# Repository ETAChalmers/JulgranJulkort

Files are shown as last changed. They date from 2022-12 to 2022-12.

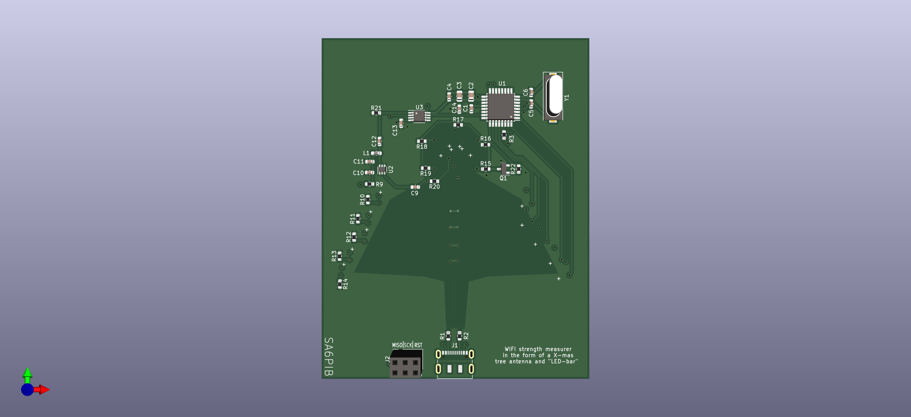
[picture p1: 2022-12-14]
ETA_JulkortB.png

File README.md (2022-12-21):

# X-mas tree card
# NOT TESTED (2022-12-21)
This PCB is a supposed to become a Christmas card from E-sectionens Teletekniska Avdelning (ETA). It is a 2,4 GHz antenna in the shape of a Christmas tree. According to the Wifi strength the card is exposed to, different LED's should light up, so it is basically a fancy bar graph.

ETA_JulkortF
ETA_JulkortB

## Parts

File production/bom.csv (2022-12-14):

Designator | Footprint | Quantity | Value | LCSC Part #
C1, C11, C4 | C_0603_1608Metric | 3 | 0,1 uF
C10 | C_0603_1608Metric | 1 | 100 pF
C12, C9 | C_0603_1608Metric | 2 | 1 nF
C13 | C_0603_1608Metric | 1 | C
C14 | C_0603_1608Metric | 1 | 0,01 uF
C2, C3 | C_0805_2012Metric | 2 | 4,7 uF
C5, C6 | C_0603_1608Metric | 2 | 22p
D1, D10, D11, D12, D13, D14, D15, D16, D2, D3, D4, D5, D6, D7, D8, D9 | LED_0805_2012Metric | 16 | LED
J1 | USB_C_Receptacle_JAE_DX07S016JA1R1500 | 1 | USB_C_Receptacle_USB2.0
J2 | PinSocket_2x03_P2.54mm_Vertical | 1 | Conn_02x03_Odd_Even
L1 | L_0603_1608Metric_Pad1.05x0.95mm_HandSolder | 1 | 28 nH
Q1 | SOT-23 | 1 | IRLML2803TR
R1, R2 | R_0603_1608Metric | 2 | 5,1k
R10, R11, R12, R13, R14, R15, R16, R17, R18, R19, R20 | R_0603_1608Metric | 11 | 500
R21, R22 | R_0603_1608Metric | 2 | 50
R3 | R_0603_1608Metric | 1 | 10k
R9 | R_0603_1608Metric | 1 | 30
U1 | TQFP-32_7x7mm_P0.8mm | 1 | ATmega88
U2 | SOT-363_SC-70-6 | 1 | AVT-51663_PIB
U3 | MSOP-8_3x3mm_P0.65mm | 1 | MAX4003
Y1 | Crystal_SMD_HC49-SD | 1 | 16MHz

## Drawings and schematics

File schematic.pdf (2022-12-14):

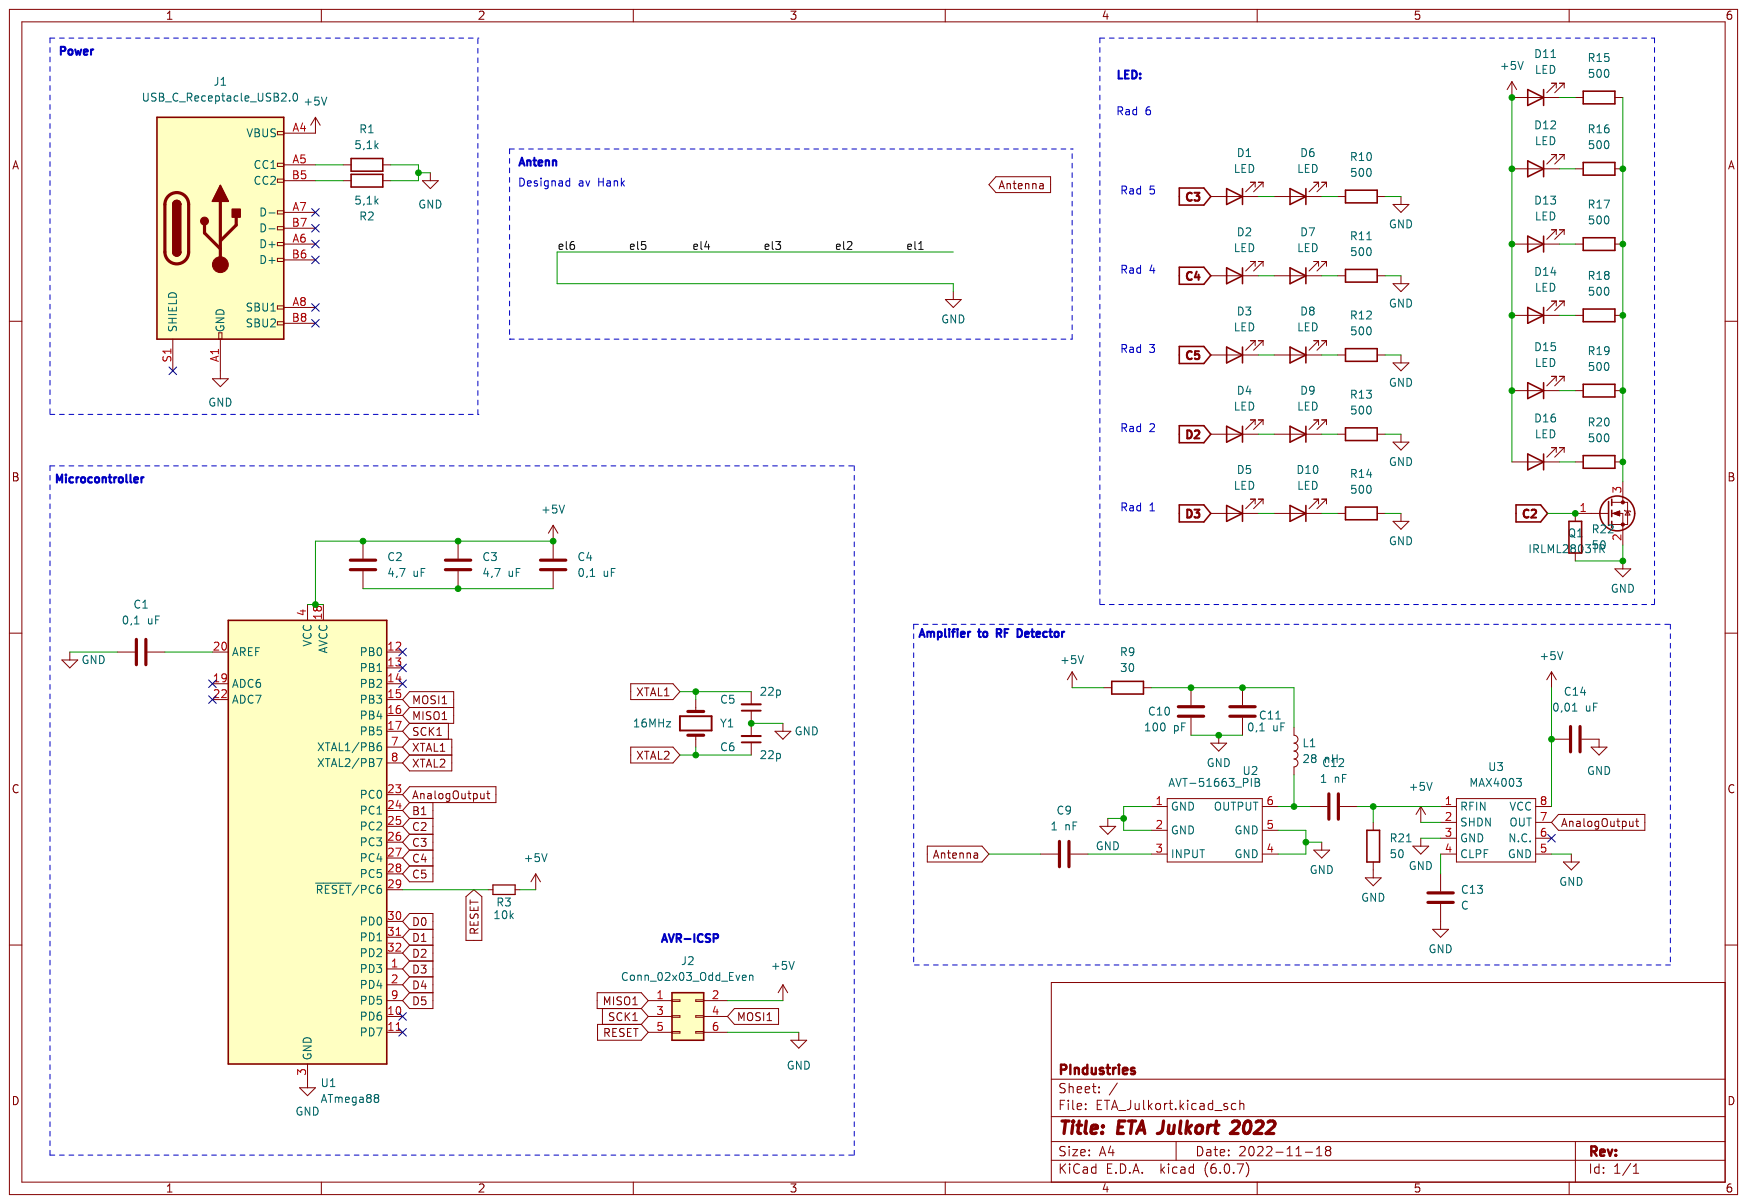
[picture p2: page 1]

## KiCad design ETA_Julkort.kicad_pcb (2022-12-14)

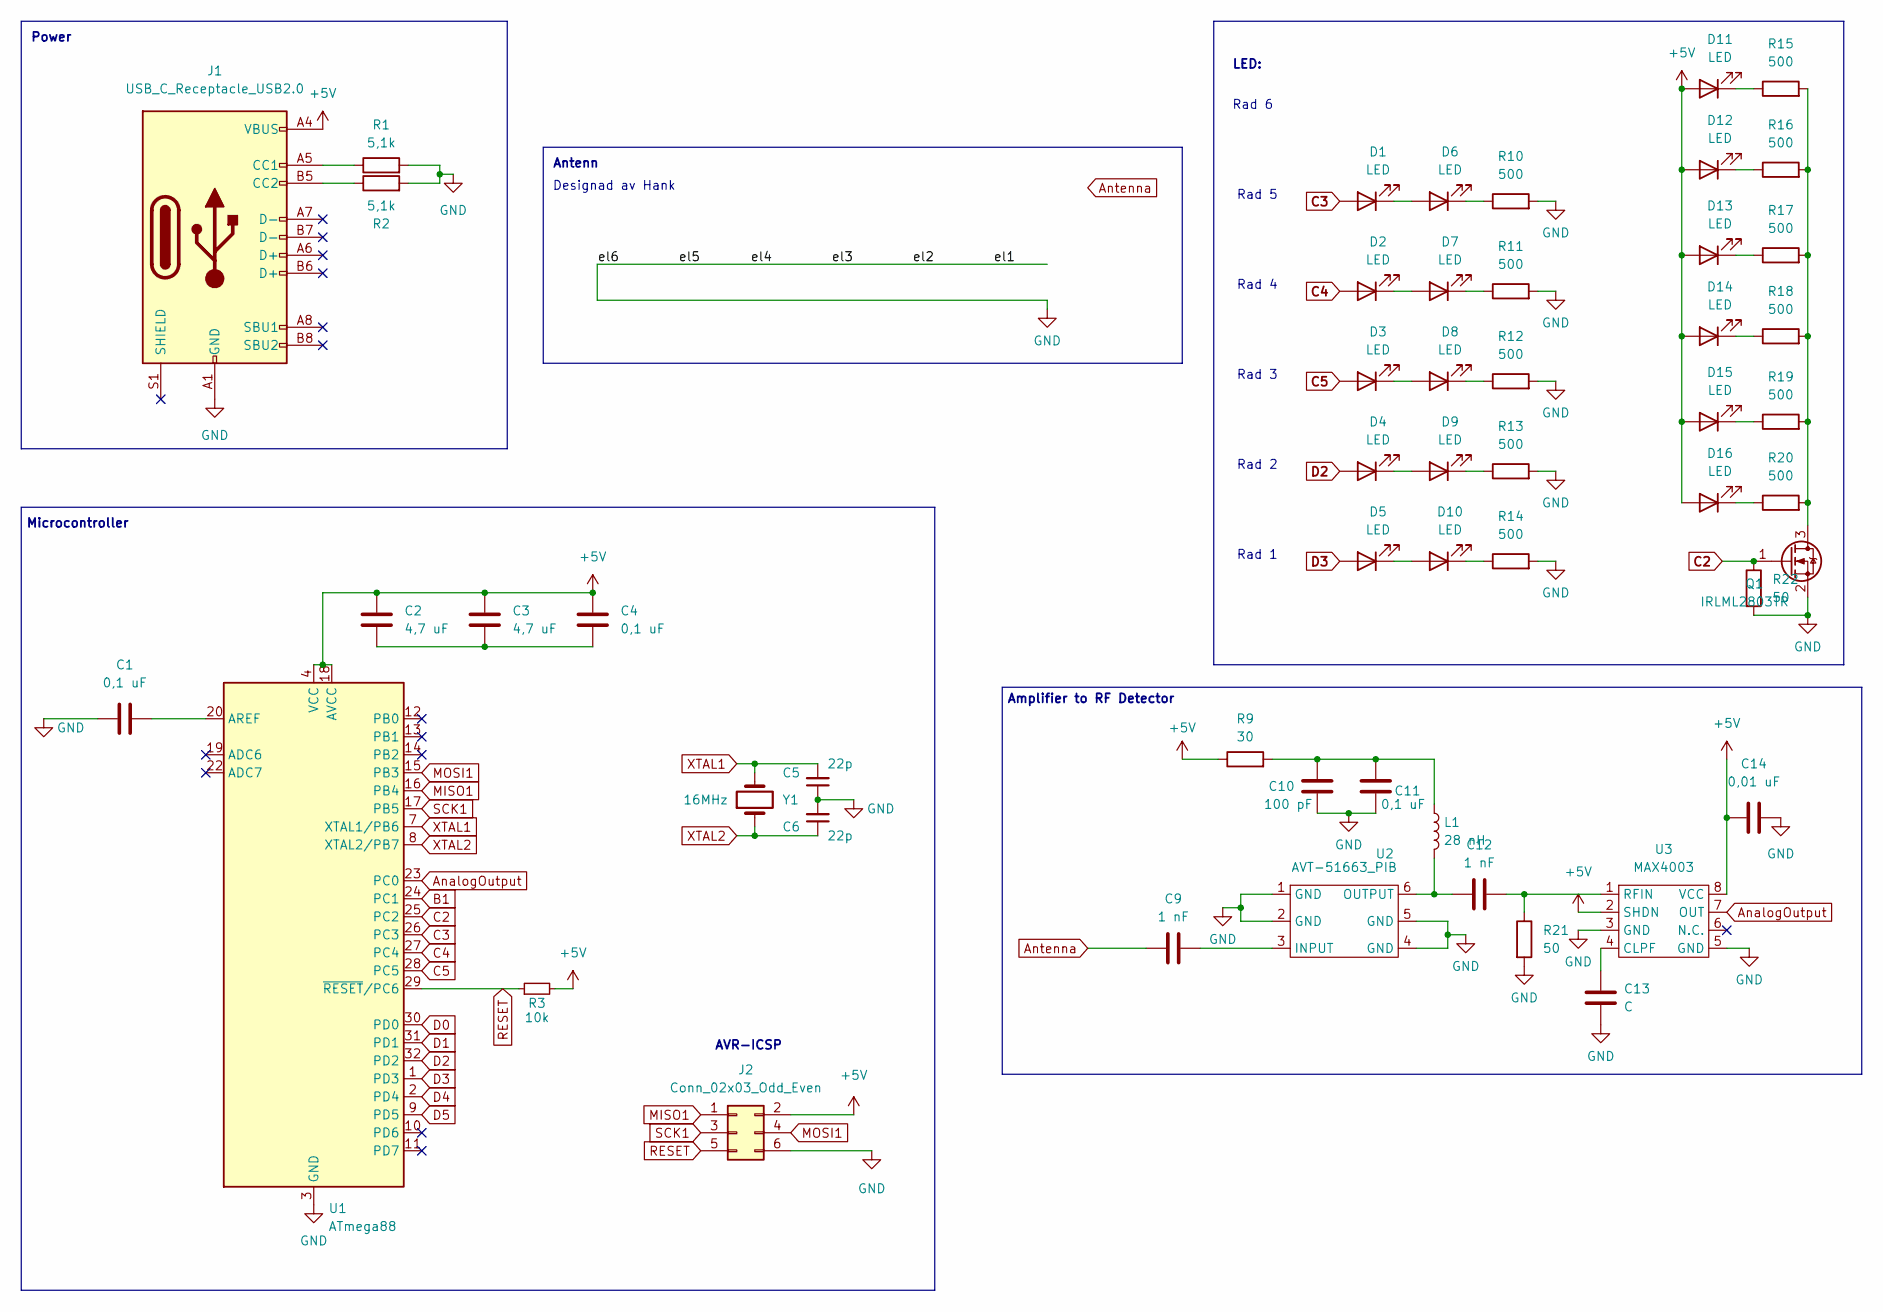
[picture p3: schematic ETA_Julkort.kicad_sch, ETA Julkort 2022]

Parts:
C1, C4, C11: 0,1 uF; C_0603_1608Metric
C2, C3: 4,7 uF; C_0805_2012Metric
C5, C6: 22p; C_0603_1608Metric
C9, C12: 1 nF; C_0603_1608Metric
C10: 100 pF; C_0603_1608Metric
C13: C; C_0603_1608Metric
C14: 0,01 uF; C_0603_1608Metric
D1, D2, D3, D4, D5, D6, D7, D8, D9, D10, D11, D12, D13, D14, D15, D16: LED; LED_0805_2012Metric
J1: USB_C_Receptacle_USB2.0; USB_C_Receptacle_JAE_DX07S016JA1R1500
J2: Conn_02x03_Odd_Even; PinSocket_2x03_P2.54mm_Vertical
L1: 28 nH; L_0603_1608Metric_Pad1.05x0.95mm_HandSolder
Q1: IRLML2803TR; SOT-23
R1, R2: 5,1k; R_0603_1608Metric
R3: 10k; R_0603_1608Metric
R9: 30; R_0603_1608Metric
R10, R11, R12, R13, R14, R15, R16, R17, R18, R19, R20: 500; R_0603_1608Metric
R21, R22: 50; R_0603_1608Metric
U1: ATmega88; TQFP-32_7x7mm_P0.8mm
U2: AVT-51663_PIB; SOT-363_SC-70-6
U3: MAX4003; MSOP-8_3x3mm_P0.65mm
Y1: 16MHz; Crystal_SMD_HC49-SD

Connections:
+5V: C2.1, C3.1, C4.1, C14.1, D11.2 (A), D12.2 (A), D13.2 (A), D14.2 (A), D15.2 (A), D16.2 (A), J1.A4 (VBUS), J1.A9 (VBUS), J1.B4 (VBUS), J1.B9 (VBUS), J2.2, R3.2, R9.1, U1.4 (VCC), U1.6 (VCC), U1.18 (AVCC), U3.2 (SHDN), U3.8 (VCC)
AnalogOutput: U1.23 (PC0), U3.7 (OUT)
B1: U1.24 (PC1)
C2: Q1.1 (G), R22.1, U1.25 (PC2)
C3: D1.2 (A), U1.26 (PC3)
C4: D2.2 (A), U1.27 (PC4)
C5: D3.2 (A), U1.28 (PC5)
D0: U1.30 (PD0)
D1: U1.31 (PD1)
D2: D4.2 (A), U1.32 (PD2)
D3: D5.2 (A), U1.1 (PD3)
D4: U1.2 (PD4)
D5: U1.9 (PD5)
MISO1: J2.1, U1.16 (PB4)
MOSI1: J2.4, U1.15 (PB3)
unnamed: C1.2, U1.20 (AREF)
unnamed: C2.2, C3.2, C4.2
unnamed: C9.2, U2.3 (INPUT)
unnamed: C10.1, C11.1, L1.1, R9.2
unnamed: C12.1, L1.2, U2.6 (OUTPUT)
unnamed: C12.2, R21.1, U3.1 (RFIN)
unnamed: C13.1, U3.4 (CLPF)
unnamed: D1.1 (K), D6.2 (A)
unnamed: D2.1 (K), D7.2 (A)
unnamed: D3.1 (K), D8.2 (A)
unnamed: D4.1 (K), D9.2 (A)
unnamed: D6.1 (K), R10.1
unnamed: D7.1 (K), R11.1
unnamed: D8.1 (K), R12.1
unnamed: D9.1 (K), R13.1
unnamed: D10.1 (K), R14.1
unnamed: D5.1 (K), D10.2 (A)
unnamed: D11.1 (K), R15.1
unnamed: D12.1 (K), R16.1
unnamed: D13.1 (K), R17.1
unnamed: D14.1 (K), R18.1
unnamed: D15.1 (K), R19.1
unnamed: D16.1 (K), R20.1
unnamed: J1.A5 (CC1), R1.1
unnamed: J1.B5 (CC2), R2.1
unnamed: Q1.3 (D), R15.2, R16.2, R17.2, R18.2, R19.2, R20.2
RESET: J2.5, R3.1, U1.29 (~RESET/PC6)
SCK1: J2.3, U1.17 (PB5)
XTAL1: C5.2, U1.7 (XTAL1/PB6), Y1.2
XTAL2: C6.1, U1.8 (XTAL2/PB7), Y1.1

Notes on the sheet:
Microcontroller
Rad 5
Rad 6
Designad av Hank
Amplifier to RF Detector
LED:
Rad 2
Antenn
Rad 4
Rad 1
Rad 3
AVR-ICSP
Power

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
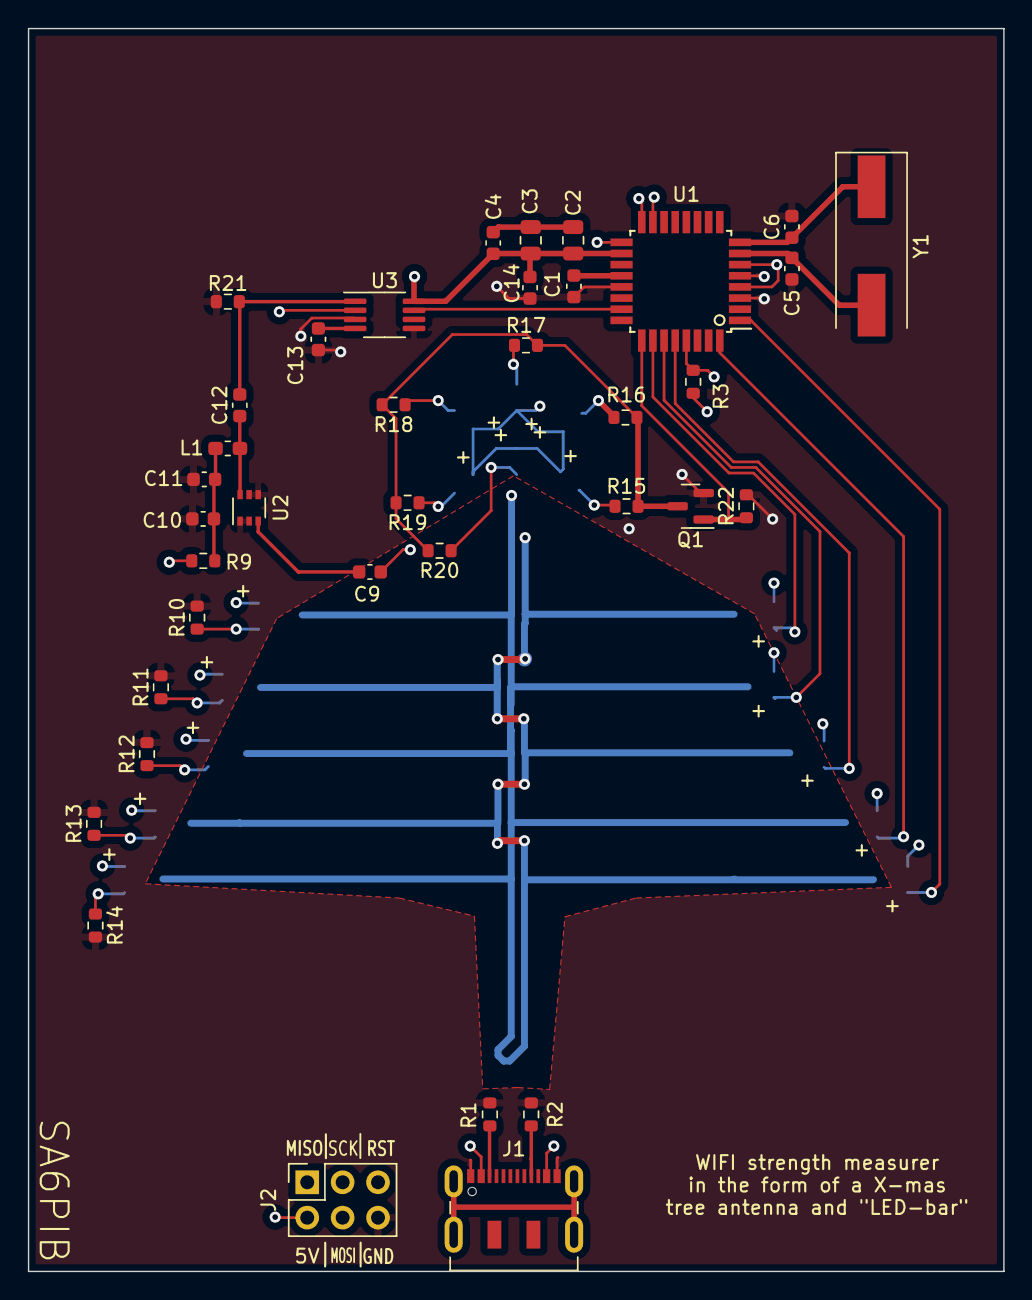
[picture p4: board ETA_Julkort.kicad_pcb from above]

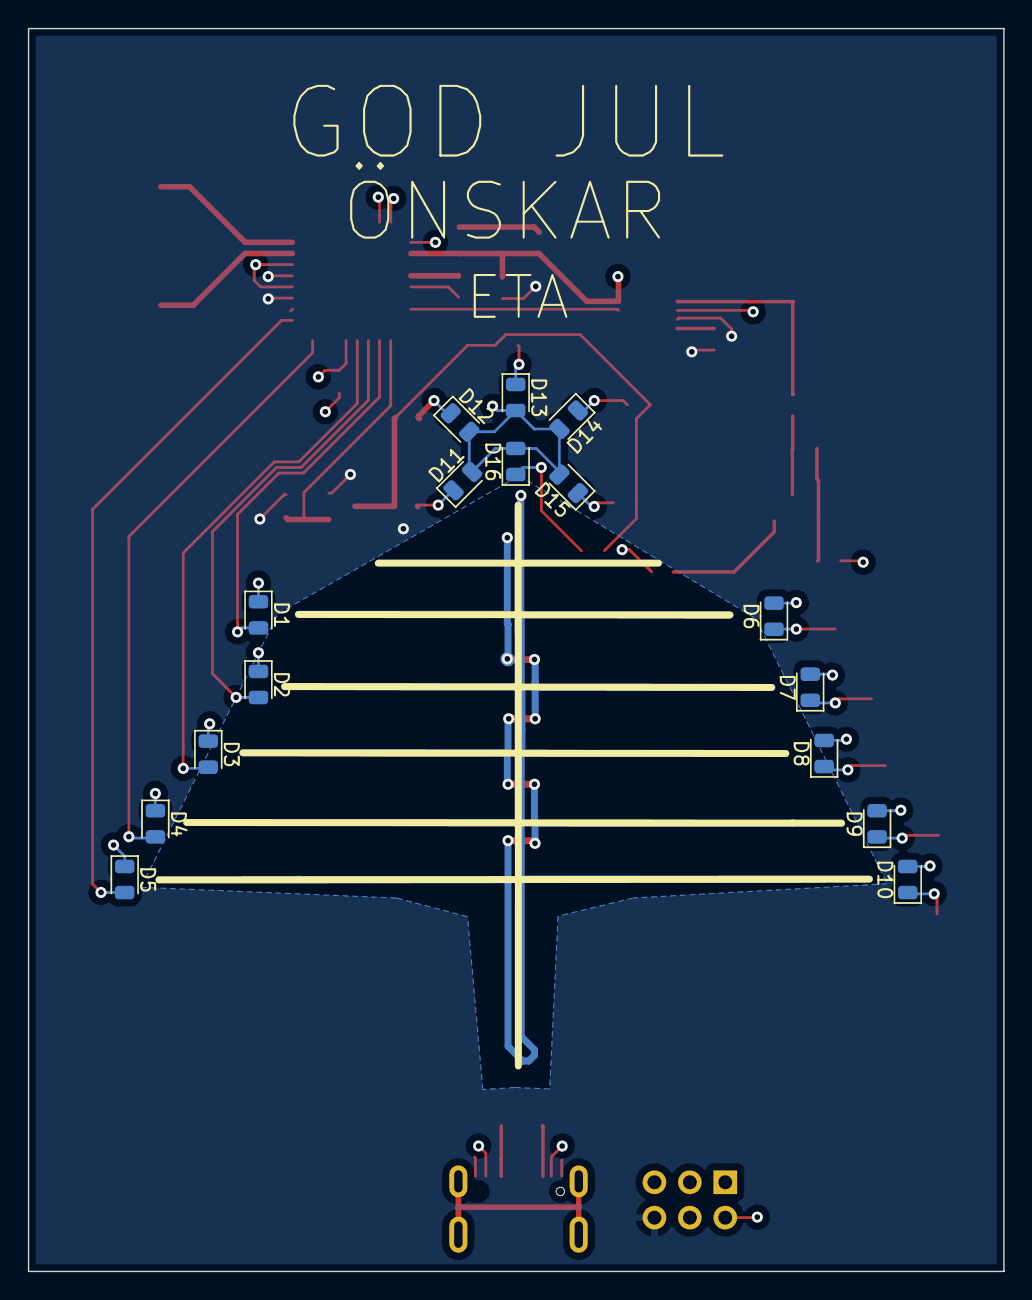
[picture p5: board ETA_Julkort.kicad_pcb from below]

Board: 4 copper layers, 70.0 x 89.2 mm, 53 parts (16 on the bottom side), 41 nets.
